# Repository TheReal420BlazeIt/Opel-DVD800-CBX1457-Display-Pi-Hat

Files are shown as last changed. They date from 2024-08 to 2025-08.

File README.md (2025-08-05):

# Raspberry Pi Hat for Opel DVD800 Navi Display
Raspberry Pi Hat for Opel DVD800 Navi Display using Sony CXB1457R GVIF Chip

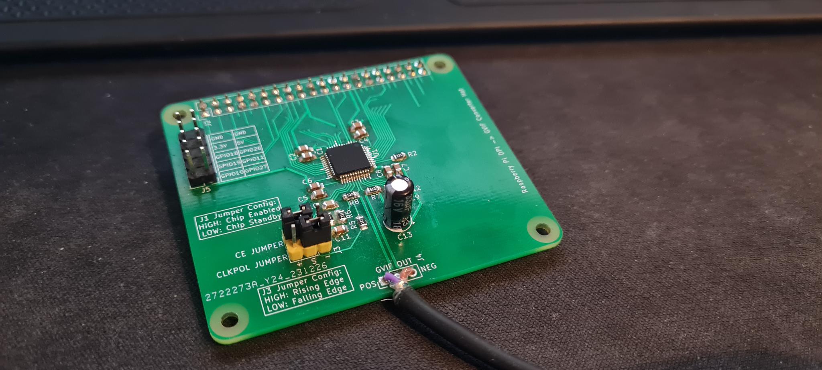
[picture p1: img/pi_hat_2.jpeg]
Raspberry Pi GVIF Hat

## Project
The reason for this project is because the original radio for my car (DVD800 Navi) is quite outdated. Old navigation maps, no Bluetooth playback, etc. So the idea was to use a Raspberry Pi as a head-unit. 
Because I like the aesthetic of the original centre console of my car, I decided to reverse engineer my car's radio original display, so it can be used with the Pi. 

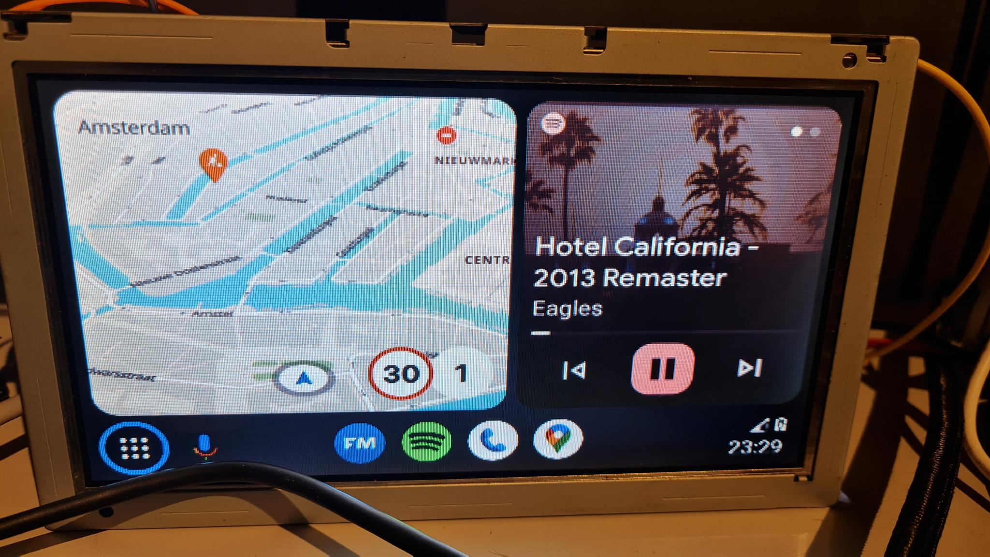
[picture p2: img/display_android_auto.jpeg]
Android Auto on origional display

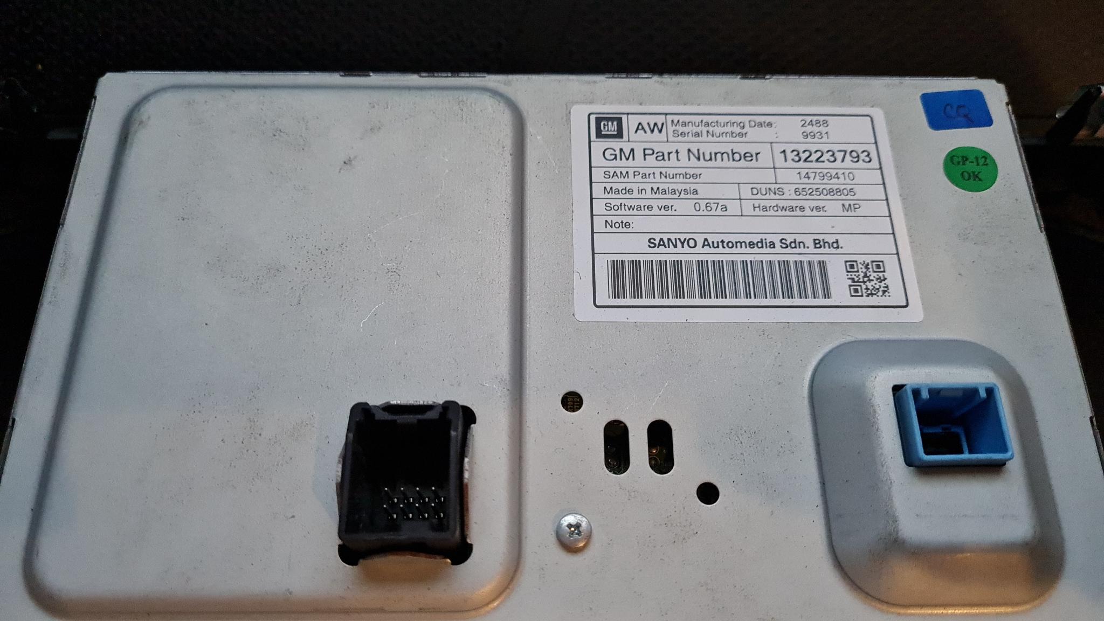
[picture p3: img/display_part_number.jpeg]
Display Part Number

## Parts
All the parts are easy to get at every electronics shop. Except for the CBX1457. It was quite hard to find the chip. I ended up with ordering one from AliExpress. Quite expensive (around 35 euro's), but it works like a charm. Another option is to salvage one from a car head-unit that uses the same video chip. I ordered the PCB from JLCPCB.

CBX1457 datasheet: https://datasheetspdf.com/pdf-down/C/X/B/CXB1457R-SonyCorporation.pdf

## Raspberry Pi config.txt
The Raspberry Pi needs to be configured to output RGB video over GPIO. To enable this, we need to add a couple of lines in the config.txt on the Pi boot partition:

    gpio=0-9=a2
    gpio=12-17=a2
    gpio=20-25=a2
        
    dtoverlay=dpi18
    overscan_left=0
    overscan_right=0
    overscan_top=0
    overscan_bottom=0
    framebuffer_width=480
    framebuffer_height=240
    enable_dpi_lcd=1
    display_default_lcd=1
    dpi_group=2
    dpi_mode=87
        
    dpi_output_format=286742
        
    dpi_timings=480 0 50 12 50 240 0 6 3 10 0 0 0 60 0 9000000 3

Documentation on Raspberry Pi DPI video: https://pip.raspberrypi.com/categories/685-whitepapers-app-notes/documents/RP-003471-WP/Using-a-DPI-display.pdf

### Update:
The config.txt above doesn't work with newer versions of Raspberry Pi OS. If the above config doesn't work for you, try this one:

    gpio=0-9=a2
    gpio=12-17=a2
    gpio=20-25=a2

    dtoverlay=vc4-kms-v3d
    dtoverlay=vc4-kms-dpi-generic,hactive=480,hfp=50,hsync=12,hbp=50
    dtparam=vactive=240,vfp=6,vsync=3,vbp=10
    dtparam=clock-frequency=9000000,rgb666-padhi
    dpi_output_format=286742

## Other Vehicles
I only tested this setup on the DVD800 Navi display of an Opel Insignia. Other Opel/Vauxhall models with the same DVD800 Navi radio system should work the same (e.g. Astra/Zafira). This display uses RGB666 video input, so only 6 bits per color are used. 

This particular setup does not use bits 0 & 1 for each color on the CBX chip. For example: the Pi's red bit 0 goes to red bit 2 on the CBX chip.

The CBX1457 chip is capable of using RGB888 video, so for some vehicles this setup may be different. 

This hat may work on other car displays that use the CBX1457 transmitter in the head unit, however, the hardware/software setup may be different. The best option is to check your car's display datasheet & inspect the display driver PCB.

### Update on other displays
I successfully tested a similar display (GM part number: 23354890). Connectors and dimentions are the same, but this type has a display resolution of 800x480, so much better than the old display. Only config.txt changes are needed. Everything else works out of the box:

    gpio=0-9=a2
    gpio=12-17=a2
    gpio=20-25=a2

    dtoverlay=vc4-kms-v3d
    dtoverlay=vc4-kms-dpi-generic,hactive=800,hfp=210,hsync=1,hbp=182
    dtparam=vactive=480,vfp=62,vsync=5,vbp=6
    dtparam=clock-frequency=33300000,rgb666-padhi
    dpi_output_format=286742

## Note
Later I noticed some minor errors in the schematic:

    R7  330R needs to be 4.7K
    C9  640p needs to be 680p (Although 640p works fine. Just based on reference design)
    C10 640p needs to be 10nF

This project is tested on Raspberry Pi 4, Compute Module 4, and Compute Module 5

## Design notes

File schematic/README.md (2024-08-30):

Schematic & PCB are made with version 7.0.10. Older versions may not work!

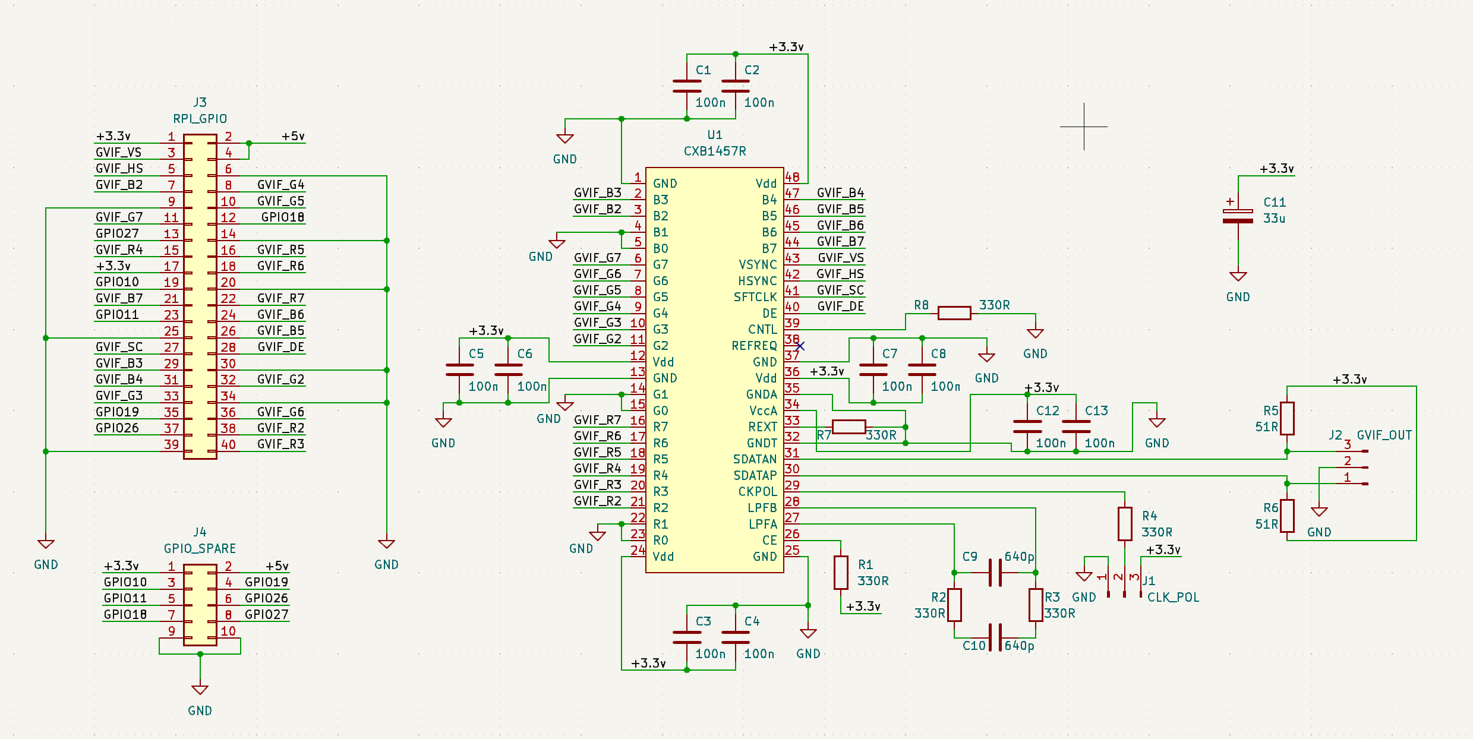
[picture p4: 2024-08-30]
img/schematic.png

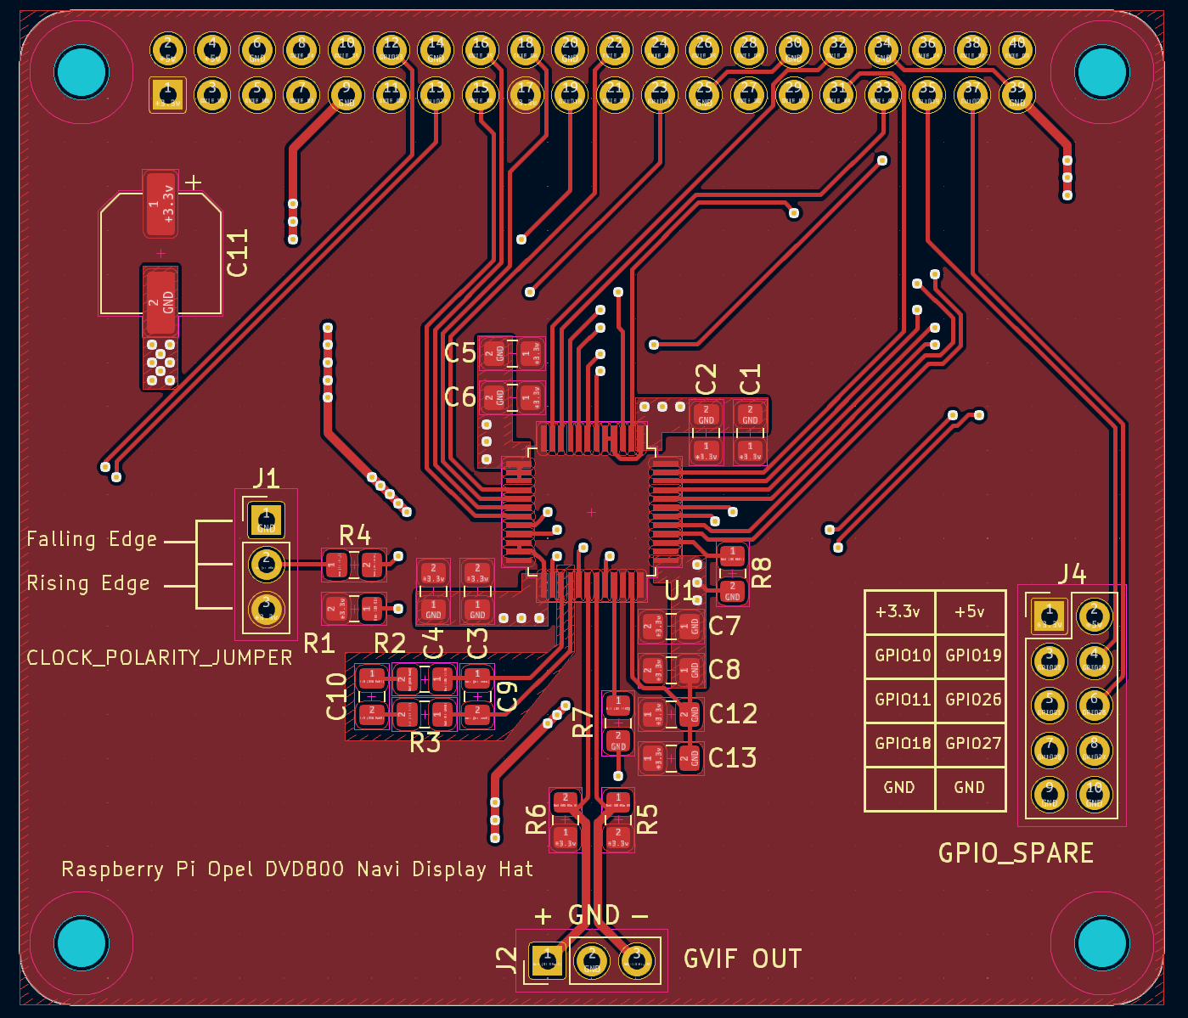
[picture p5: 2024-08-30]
img/pcb_front.png

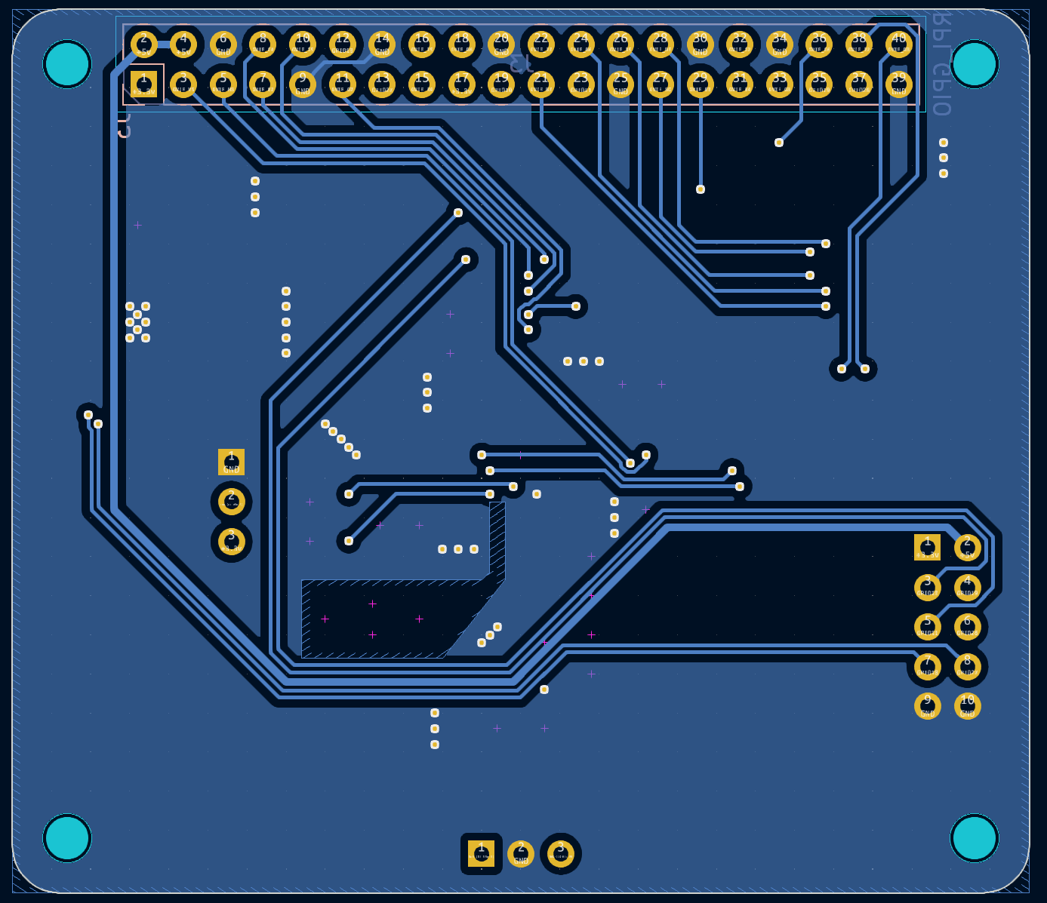
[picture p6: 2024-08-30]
img/pcb_back.png

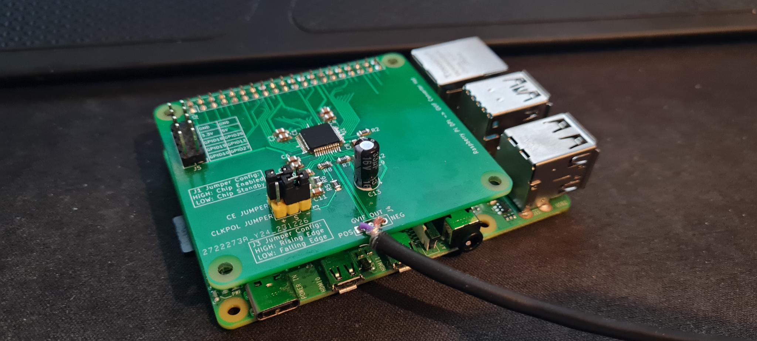
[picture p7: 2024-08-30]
img/pi_hat_1.jpeg

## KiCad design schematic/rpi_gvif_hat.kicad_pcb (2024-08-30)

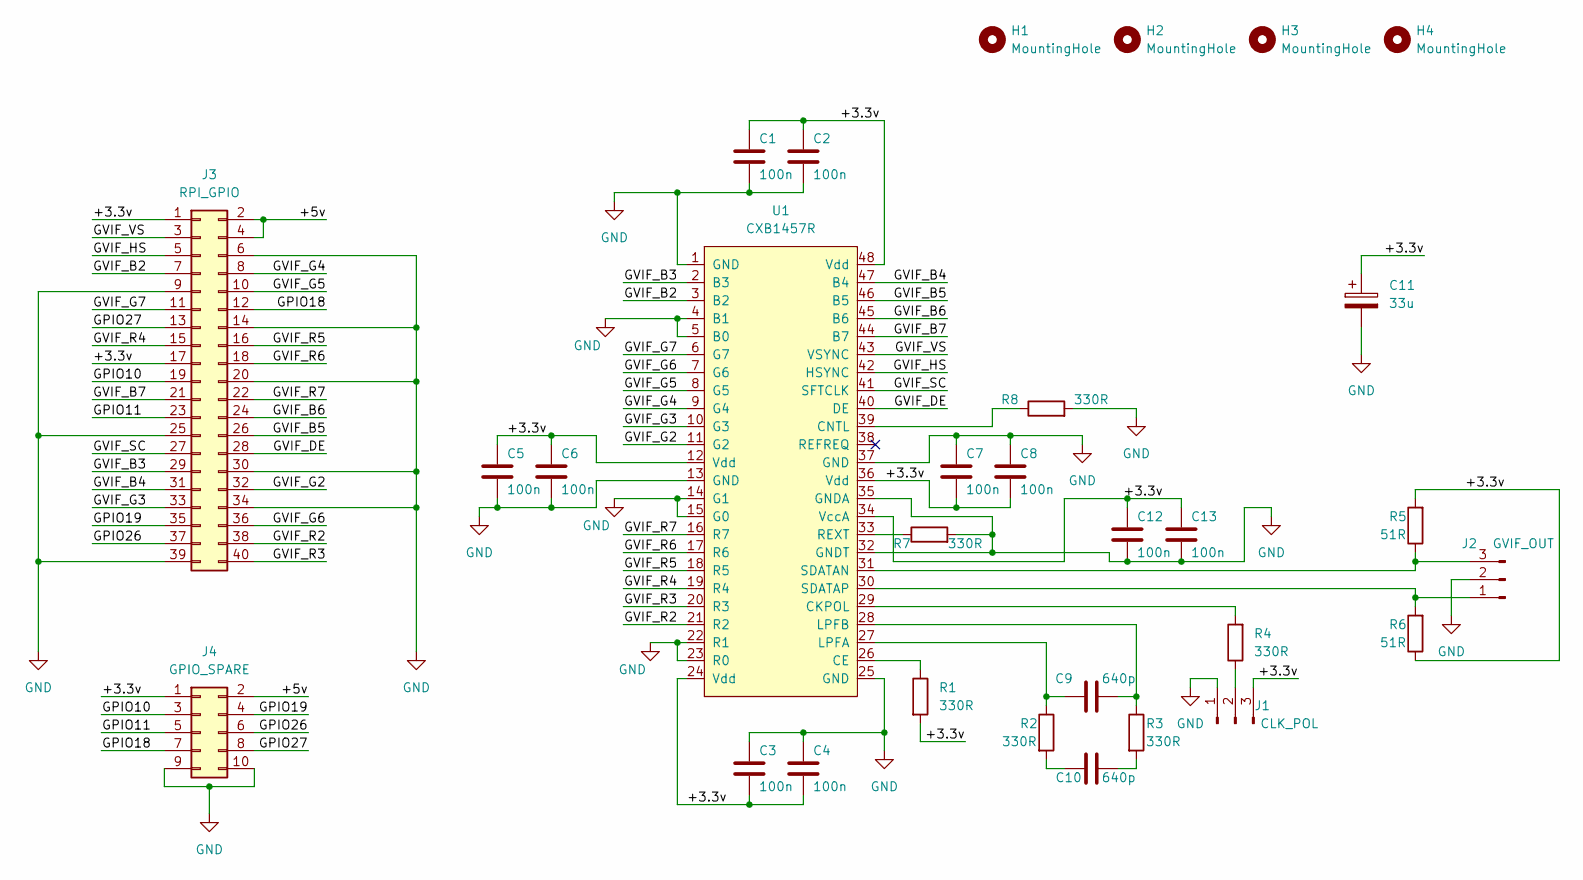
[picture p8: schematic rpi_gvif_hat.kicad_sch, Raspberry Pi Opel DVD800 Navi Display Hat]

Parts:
C1, C2, C3, C4, C5, C6, C7, C8, C12, C13: 100n; C_0805_2012Metric_Pad1.18x1.45mm_HandSolder
C9, C10: 640p; C_0805_2012Metric_Pad1.18x1.45mm_HandSolder
C11: 33u; CP_Elec_6.3x5.4
H1, H2, H3, H4: MountingHole; MountingHole_2.7mm_M2.5
J1: CLK_POL; PinHeader_1x03_P2.54mm_Vertical
J2: GVIF_OUT; PinHeader_1x03_P2.54mm_Vertical
J3: RPI_GPIO; PinSocket_2x20_P2.54mm_Vertical
J4: GPIO_SPARE; PinHeader_2x05_P2.54mm_Vertical
R1, R2, R3, R4, R7, R8: 330R; R_0805_2012Metric_Pad1.20x1.40mm_HandSolder
R5, R6: 51R; R_0805_2012Metric_Pad1.20x1.40mm_HandSolder
U1: CXB1457R; LQFP-48_7x7mm_P0.5mm

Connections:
/+3.3v: C1.1, C2.1, C3.2, C4.2, C5.1, C6.1, C7.2, C8.2, C11.1, C12.1, C13.1, J1.3, J3.1, J3.17, J4.1, R1.2, R5.2, R6.1, U1.12 (Vdd), U1.24 (Vdd), U1.34 (VccA), U1.36 (Vdd), U1.48 (Vdd)
/+5v: J3.2, J3.4, J4.2
/GPIO10: J3.19, J4.3
/GPIO11: J3.23, J4.5
/GPIO18: J3.12, J4.7
/GPIO19: J3.35, J4.4
/GPIO26: J3.37, J4.6
/GPIO27: J3.13, J4.8
/GVIF_B2: J3.7, U1.3 (B2)
/GVIF_B3: J3.29, U1.2 (B3)
/GVIF_B4: J3.31, U1.47 (B4)
/GVIF_B5: J3.26, U1.46 (B5)
/GVIF_B6: J3.24, U1.45 (B6)
/GVIF_B7: J3.21, U1.44 (B7)
/GVIF_DE: J3.28, U1.40 (DE)
/GVIF_G2: J3.32, U1.11 (G2)
/GVIF_G3: J3.33, U1.10 (G3)
/GVIF_G4: J3.8, U1.9 (G4)
/GVIF_G5: J3.10, U1.8 (G5)
/GVIF_G6: J3.36, U1.7 (G6)
/GVIF_G7: J3.11, U1.6 (G7)
/GVIF_HS: J3.5, U1.42 (HSYNC)
/GVIF_R2: J3.38, U1.21 (R2)
/GVIF_R3: J3.40, U1.20 (R3)
/GVIF_R4: J3.15, U1.19 (R4)
/GVIF_R5: J3.16, U1.18 (R5)
/GVIF_R6: J3.18, U1.17 (R6)
/GVIF_R7: J3.22, U1.16 (R7)
/GVIF_SC: J3.27, U1.41 (SFTCLK)
/GVIF_VS: J3.3, U1.43 (VSYNC)
GND: C1.2, C2.2, C3.1, C4.1, C5.2, C6.2, C7.1, C8.1, C11.2, C12.2, C13.2, J1.1, J2.2, J3.6, J3.9, J3.14, J3.20, J3.25, J3.30, J3.34, J3.39, J4.9, J4.10, R7.2, R8.2, U1.1 (GND), U1.4 (B1), U1.5 (B0), U1.13 (GND), U1.14 (G1), U1.15 (G0), U1.22 (R1), U1.23 (R0), U1.25 (GND), U1.32 (GNDT), U1.35 (GNDA), U1.37 (GND)
unnamed: C10.1, R2.2
unnamed: C10.2, R3.2
unnamed: J1.2, R4.1
unnamed: J2.1, R6.2, U1.30 (SDATAP)
unnamed: J2.3, R5.1, U1.31 (SDATAN)
unnamed: R1.1, U1.26 (CE)
unnamed: R4.2, U1.29 (CKPOL)
unnamed: R8.1, U1.39 (CNTL)
unnamed: C9.1, R2.1, U1.27 (LPFA)
unnamed: C9.2, R3.1, U1.28 (LPFB)
unnamed: R7.1, U1.33 (REXT)

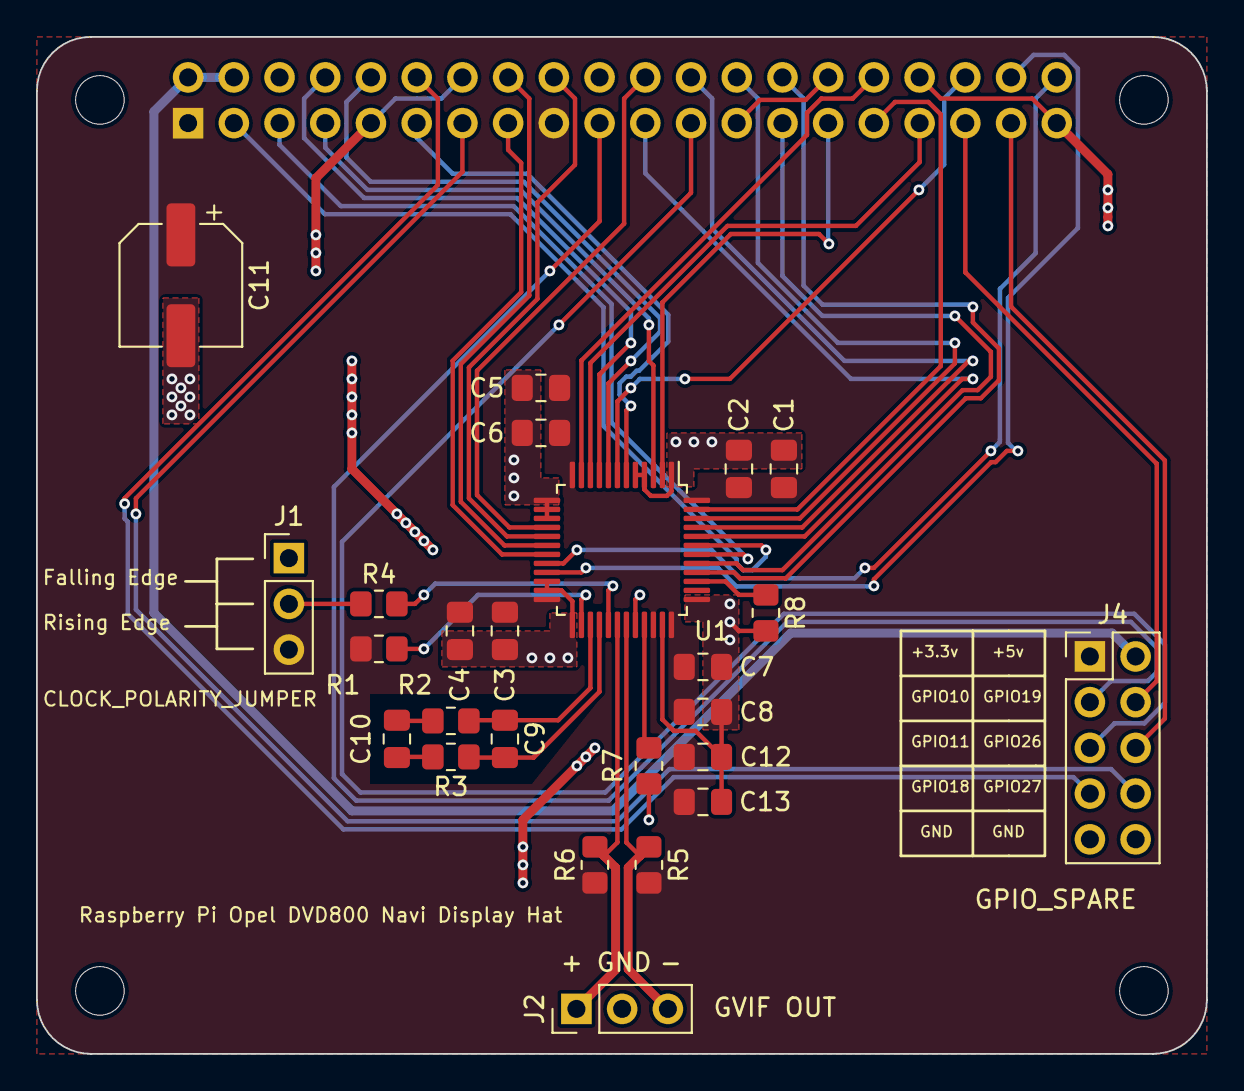
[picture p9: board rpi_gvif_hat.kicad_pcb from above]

Board: 2 copper layers, 65.0 x 56.5 mm, 30 parts (1 on the bottom side), 42 nets.

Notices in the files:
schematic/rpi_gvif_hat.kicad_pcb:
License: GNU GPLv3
